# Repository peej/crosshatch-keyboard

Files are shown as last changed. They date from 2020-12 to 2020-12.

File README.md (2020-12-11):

# Crosshatch - Through-hole ortholinear 60% keyboard PCB

Crosshatch is a 12 column ortholinear keyboard PCB using through-hole components only.

The goal of this project is to build an all through-hole component ortholinear PCB that fits in a standard 60% tray mount case.

Inspired by the [Plaid keyboard](https://github.com/hsgw/plaid).

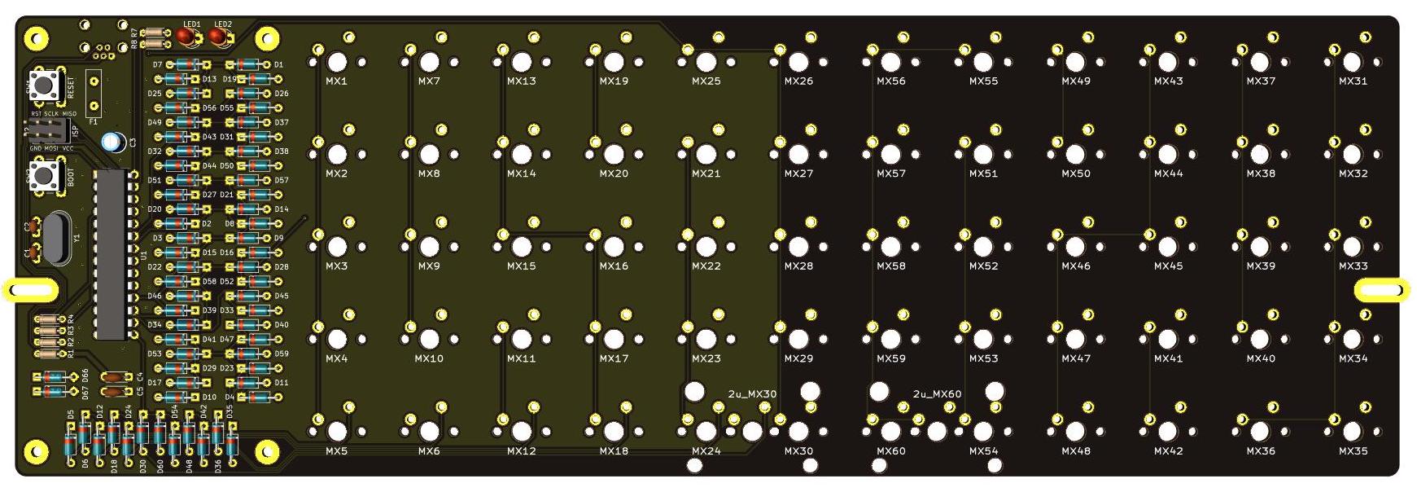
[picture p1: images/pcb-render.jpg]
PCB render


* Designed to be easy to build with minimal soldering experience.
* All through-hole components, no SMD soldering required.
* Get that visible component aesthetic in a standard 60% tray-mount case.
* Plateless.

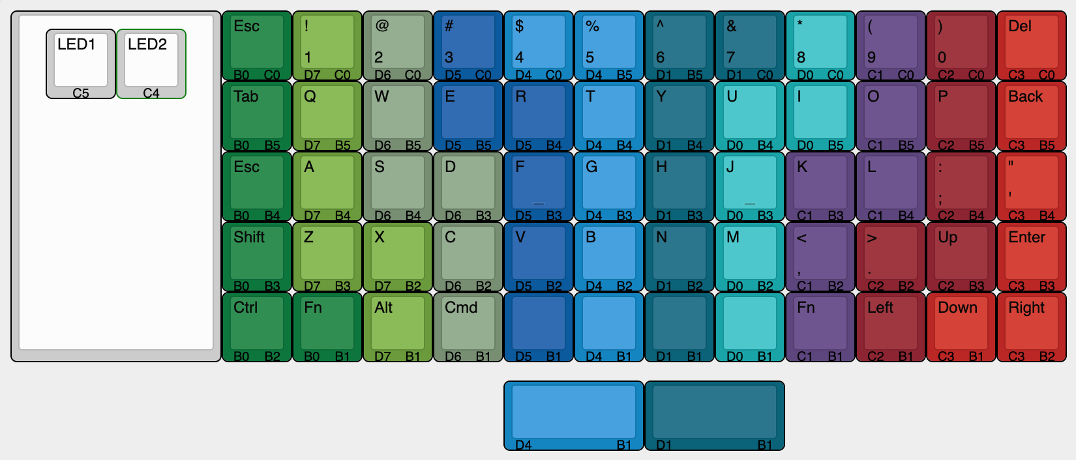
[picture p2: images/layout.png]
Layout options


# Bill of Materials (BOM)

|Ref|num||
| :- |  :- |  :- |
|C1,C2|2|multilayer ceramic capacitor 22pF or 20pF|
|C3|1|electrolytic capacitor 10uF|
|C4,C5|2|multilayer ceramic capacitor 0.1uF|
|D1-60|60|diode 1n4148|
|D66,D67|2|zener diode 3.6V|
|F1|1|polyfuse 100mA|
|J1|1|USB miniB connector Omron XM7D-0512 or equivalent|
|J2|1|2x3 pin header|
|LED1|1|3mm LED red|
|MX1-60|60|MX PCB mount (5 pin) keyboard switch|
|R1,R7|3|resistor 1.5kΩ|
|R2,R3|2|resistor 75Ω|
|R4|1|resistor 10kΩ|
|SW50,SW51|2|tactile switch|
|U1|1|ATMEGA328P|
|Y1|1|crystal 16MHz|
|PCB|1||
|stabilizer|0-2|switch stabilizer for optional 2u keys|
|cover|1|acrylic component cover|
|screw|8|M2 8mm|
|standoff|4|M2 10mm|

# Ordering PCBs

PCBs can be manufactuered by a variety of online PCB fabricators. You can use [PCBShopper](https://pcbshopper.com/) to search for the best price.

The zip file in the gerber directory contains the gerber files your fabricator will need to make the PCB [lumberjack.zip](https://github.com/peej/crosshatch-keyboard/blob/master/gerber/crosshatch.zip) PCB.

When uploading the gerber zip files, use the default PCB settings.

# Construction

TBD

# Bootloader

TBD

# Firmware

TBD

# Component cover

95x38mm 2mm thick acrylic

TBD

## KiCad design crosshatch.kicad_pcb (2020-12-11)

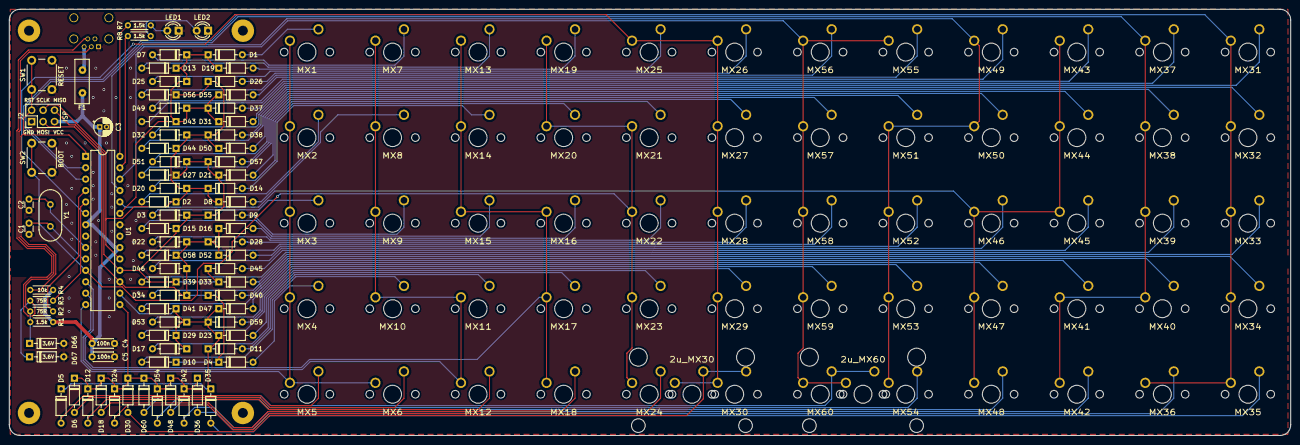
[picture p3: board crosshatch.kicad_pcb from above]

Board: 2 copper layers, 285.4 x 94.9 mm, 150 parts (1 on the bottom side), 90 nets.

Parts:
2u_MX30, 2u_MX60: SW_Push; MX_PCB_200B
C1, C2: 22p; C_Disc_D3.0mm_W1.6mm_P2.50mm
C3: 4.7u; CP_Radial_D4.0mm_P1.50mm
C4, C5: 100n; C_Disc_D4.3mm_W1.9mm_P5.00mm
D1, D2, D3, D4, D5, D6, D7, D8, D9, D10, D11, D12, D13, D14, D15, D16, D17, D18, D19, D20, D21, D22, D23, D24, D25, D26, D27, D28, D29, D30, D31, D32, D33, D34, D35, D36, D37, D38, D39, D40, D41, D42, D43, D44, D45, D46, D47, D48, D49, D50, D51, D52, D53, D54, D55, D56, D57, D58, D59, D60: 1N4148; D_DO-35_SOD27_P7.62mm_Horizontal
D66, D67: 3.6V; D_DO-35_SOD27_P7.62mm_Horizontal
F1: 100mA; Fuse_Bourns_MF-RHT100
H1, H2, H3, H4: M2; MountingHole_M2
H5, H6: M2; MountingSlot_M2
J1: USB_OTG; USB_Mini-B
J2: AVR_ISP_6; PinHeader_2x03_P2.54mm_Vertical
LED1: RED; LED_D3.0mm
LED2: GREEN; LED_D3.0mm
MX1, MX2, MX3, MX4, MX5, MX6, MX7, MX8, MX9, MX10, MX11, MX12, MX13, MX14, MX15, MX16, MX17, MX18, MX19, MX20, MX21, MX22, MX23, MX24, MX25, MX26, MX27, MX28, MX29, MX30, MX31, MX32, MX33, MX34, MX35, MX36, MX37, MX38, MX39, MX40, MX41, MX42, MX43, MX44, MX45, MX46, MX47, MX48, MX49, MX50, MX51, MX52, MX53, MX54, MX55, MX56, MX57, MX58, MX59, MX60: SW_Push; MX
R1, R7, R8: 1.5k; R_Axial_DIN0204_L3.6mm_D1.6mm_P5.08mm_Horizontal
R2, R3: 75R; R_Axial_DIN0204_L3.6mm_D1.6mm_P5.08mm_Horizontal
R4: 10k; R_Axial_DIN0204_L3.6mm_D1.6mm_P5.08mm_Horizontal
SW1: RESET; SW_PUSH_6mm
SW2: BOOT; SW_PUSH_6mm
U1: ATMEGA328-PU; DIP-28_W7.62mm
Y1: 16MHz; Crystal_HC49-4H_Vertical

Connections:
+5V: C3.1, C4.1, C5.1, F1.2, J2.5, R1.2, R4.1, U1.7, U1.20
/COL0: MX1.2, MX2.2, MX3.2, MX4.2, MX5.2, MX6.2, U1.14
/COL1: MX7.2, MX8.2, MX9.2, MX10.2, MX11.2, MX12.2, U1.13
/COL2: MX13.2, MX14.2, MX15.2, MX16.2, MX17.2, MX18.2, U1.12
/COL3: MX19.2, MX20.2, MX21.2, MX22.2, MX23.2, MX24.2, SW2.1, U1.11
/COL4: 2u_MX30.2, MX25.2, MX26.2, MX27.2, MX28.2, MX29.2, MX30.2, U1.6
/COL5: MX31.2, MX32.2, MX33.2, MX34.2, MX35.2, MX36.2, U1.3
/COL6: MX37.2, MX38.2, MX39.2, MX40.2, MX41.2, MX42.2, U1.2
/COL7: MX43.2, MX44.2, MX45.2, MX46.2, MX47.2, MX48.2, U1.24
/COL8: MX49.2, MX50.2, MX51.2, MX52.2, MX53.2, MX54.2, U1.25
/COL9: 2u_MX60.2, MX55.2, MX56.2, MX57.2, MX58.2, MX59.2, MX60.2, U1.26
/LED1: R7.1, U1.28
/LED2: R8.1, U1.27
/RESET: J2.2, R4.2, SW1.1, U1.1
/ROW0: D1.1, D7.1, D13.1, D19.1, D25.1, D31.1, D37.1, D43.1, D49.1, D55.1, U1.23
/ROW1: D2.1, D8.1, D14.1, D20.1, D26.1, D32.1, D38.1, D44.1, D50.1, D56.1, J2.4, U1.19
/ROW2: D3.1, D9.1, D15.1, D21.1, D27.1, D33.1, D39.1, D45.1, D51.1, D57.1, J2.6, U1.18
/ROW3: D4.1, D10.1, D16.1, D22.1, D28.1, D34.1, D40.1, D46.1, D52.1, D58.1, J2.3, U1.17
/ROW4: D5.1, D11.1, D17.1, D23.1, D29.1, D35.1, D41.1, D47.1, D53.1, D59.1, U1.16
/ROW5: D6.1, D12.1, D18.1, D24.1, D30.1, D36.1, D42.1, D48.1, D54.1, D60.1, U1.15
/USB_D+: R2.1, U1.4
/USB_D-: R3.1, U1.5
GND: C1.2, C2.2, C3.2, C4.2, C5.2, D66.2, D67.2, J1.5, J2.1, LED1.1, LED2.1, SW1.2, SW2.2, U1.8, U1.22
unnamed: 2u_MX30.1, D30.2, MX30.1
unnamed: 2u_MX60.1, D60.2, MX60.1
unnamed: C1.1, U1.10, Y1.2
unnamed: C2.1, U1.9, Y1.1
unnamed: D1.2, MX1.1
unnamed: D2.2, MX2.1
unnamed: D3.2, MX3.1
unnamed: D4.2, MX4.1
unnamed: D5.2, MX5.1
unnamed: D6.2, MX6.1
unnamed: D7.2, MX7.1
unnamed: D8.2, MX8.1
unnamed: D9.2, MX9.1
unnamed: D10.2, MX10.1
unnamed: D11.2, MX11.1
unnamed: D12.2, MX12.1
unnamed: D13.2, MX13.1
unnamed: D14.2, MX14.1
unnamed: D15.2, MX15.1
unnamed: D16.2, MX16.1
unnamed: D17.2, MX17.1
unnamed: D18.2, MX18.1
unnamed: D19.2, MX19.1
unnamed: D20.2, MX20.1
unnamed: D21.2, MX21.1
unnamed: D22.2, MX22.1
unnamed: D23.2, MX23.1
unnamed: D24.2, MX24.1
unnamed: D25.2, MX25.1
unnamed: D26.2, MX26.1
unnamed: D27.2, MX27.1
unnamed: D28.2, MX28.1
unnamed: D29.2, MX29.1
unnamed: D31.2, MX31.1
unnamed: D32.2, MX32.1
unnamed: D33.2, MX33.1
unnamed: D34.2, MX34.1
unnamed: D35.2, MX35.1
unnamed: D36.2, MX36.1
unnamed: D37.2, MX37.1
unnamed: D38.2, MX38.1
unnamed: D39.2, MX39.1
unnamed: D40.2, MX40.1
unnamed: D41.2, MX41.1
unnamed: D42.2, MX42.1
unnamed: D43.2, MX43.1
unnamed: D44.2, MX44.1
unnamed: D45.2, MX45.1
unnamed: D46.2, MX46.1
unnamed: D47.2, MX47.1
unnamed: D48.2, MX48.1
unnamed: D49.2, MX49.1
unnamed: D50.2, MX50.1
unnamed: D51.2, MX51.1
unnamed: D52.2, MX52.1
unnamed: D53.2, MX53.1
unnamed: D54.2, MX54.1
unnamed: D55.2, MX55.1
unnamed: D56.2, MX56.1
unnamed: D57.2, MX57.1
unnamed: D58.2, MX58.1
unnamed: D59.2, MX59.1
unnamed: D66.1, J1.3, R1.1, R2.2
unnamed: D67.1, J1.2, R3.2
unnamed: F1.1, J1.1
unnamed: LED1.2, R7.2
unnamed: LED2.2, R8.2
